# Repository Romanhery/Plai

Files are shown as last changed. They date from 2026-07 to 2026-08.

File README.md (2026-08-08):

# Plai-Hackpad
Plai is a 3x3 key macropad with a rotary encoder, an OLED Display. It uses KMK firmware
I made this so that I can learn PCB design, CAD, and Programming. It has upgraded and helped me with my experience.
# Features:
<ul>
   <li>128x32 OLED Display to show a cool message</li>
   <li>EC11 Rotary encoder to change volume</li>
   <li>9 keys for the shorcuts and media control</li>
</ul>
# PCB:
   <h2>Schematic</h2>
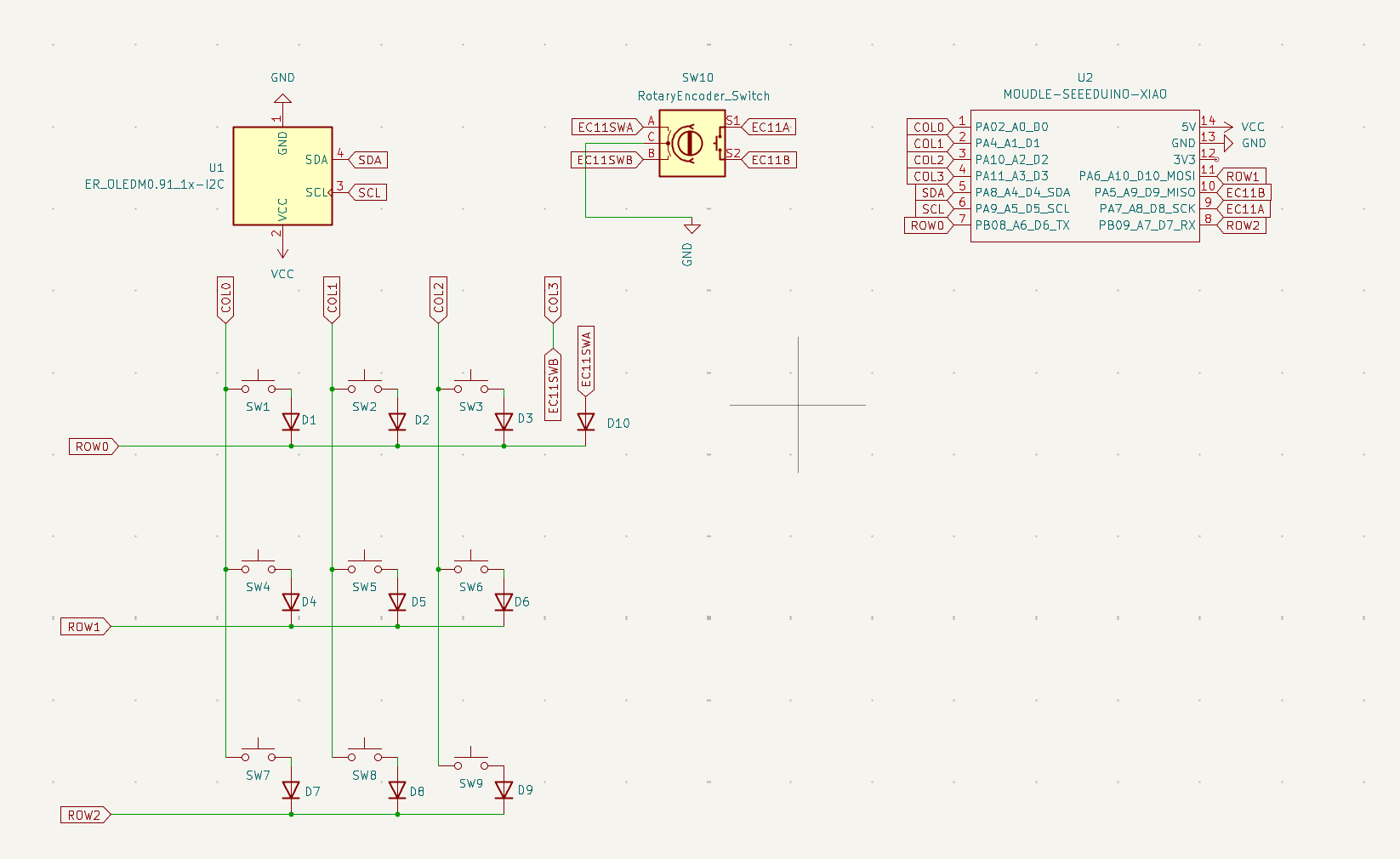
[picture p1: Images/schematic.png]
Schematic
   
   <h2>PCB</h2>
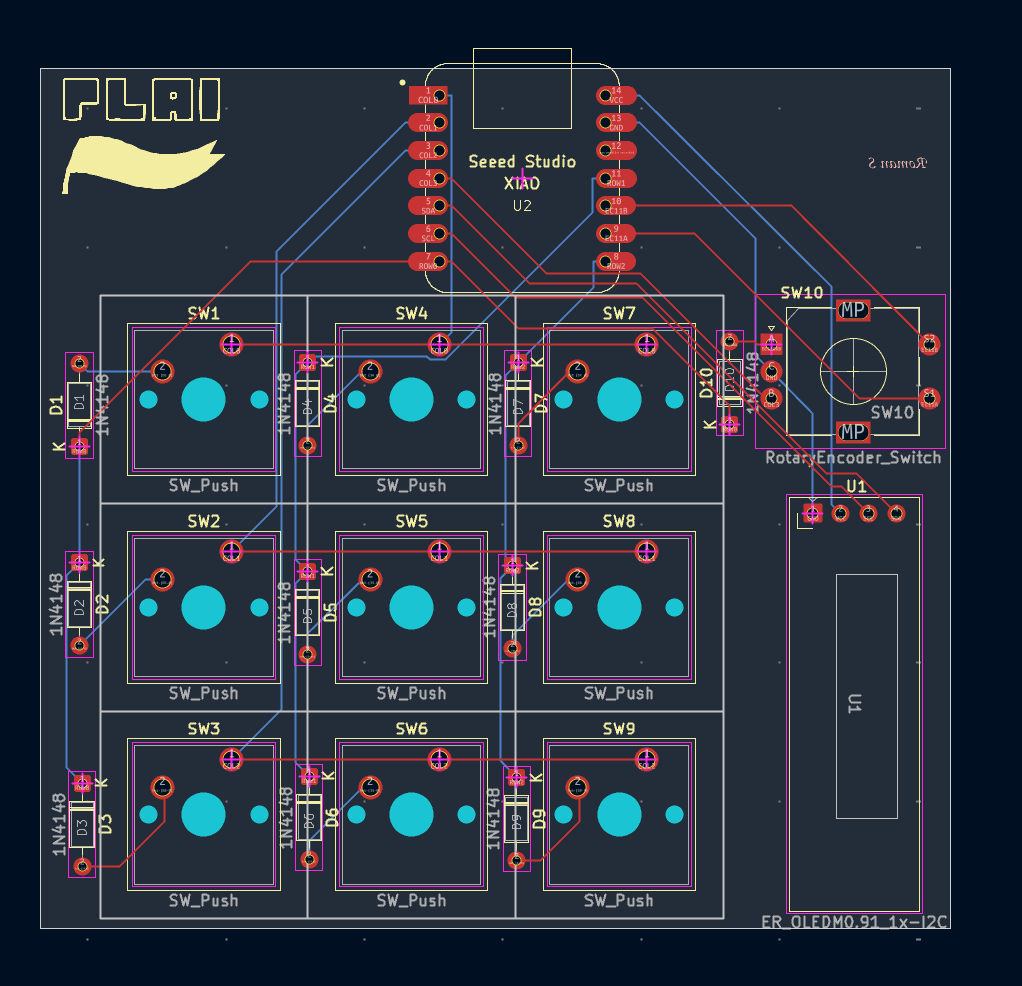
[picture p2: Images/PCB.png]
PCB
   
   <p>Made in <a href="https://www.kicad.org/">Ki-CAD</a></p> 

# CAD:
   <p>Everything is held together by using 5 M3 Bolts and heat inserts.</p>
   <p>It has 2 printed pieces to cover the electronics and house them.</p>
   <p>Made in Fusion 360</p>
<p align="center">
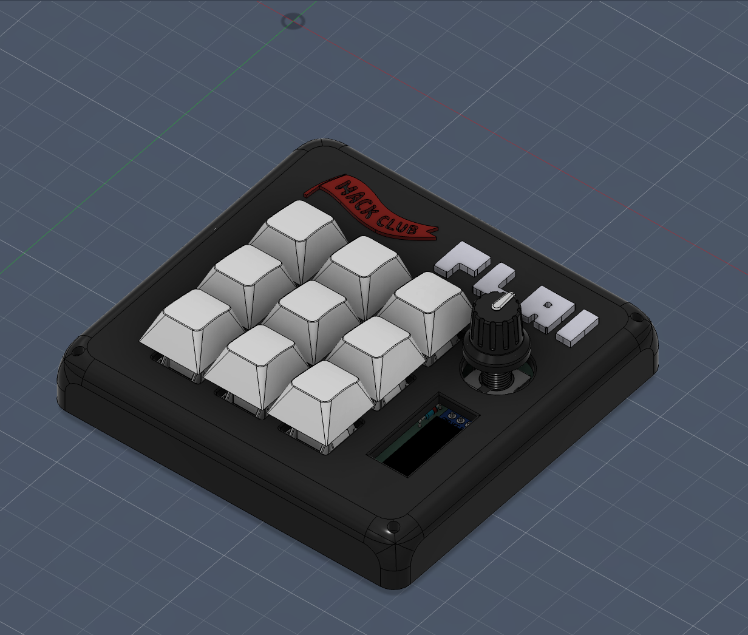
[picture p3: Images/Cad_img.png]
Plai CAD Render
  
</p>
# Firmware:
   <p>Made with <a href="https://github.com/KMKfw/kmk_firmware">KMK</a> firmware</p> 
   <h3>Features</h3>
   <li>Volume control if you twist the rotary encoder and if you press the encoder to mute</li>
   <li>Screen displays cool message</li>
   <li>They have macros for any shorcut you want (I have those right now for me)</li>
   <p align="center">
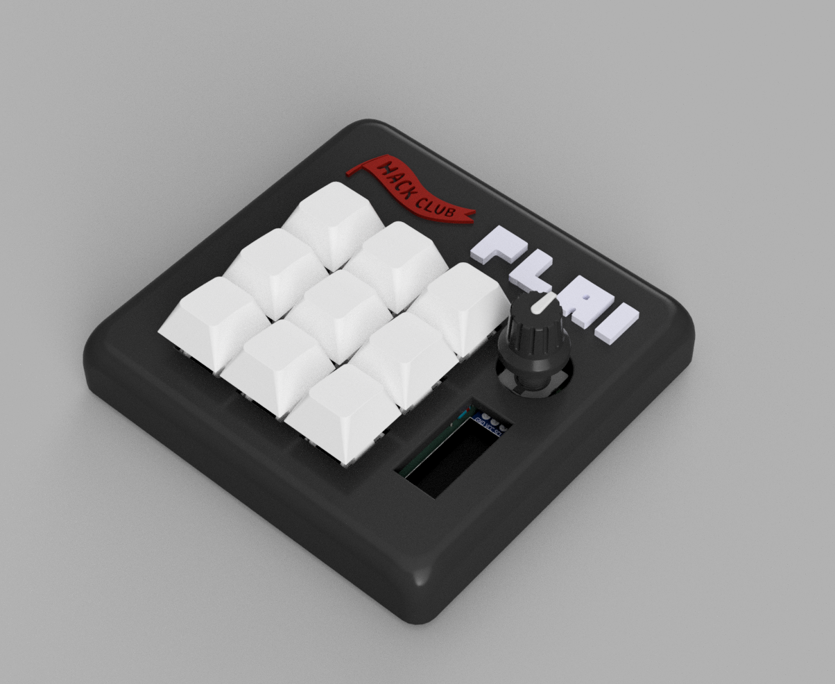
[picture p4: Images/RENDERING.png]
  
   </p>
# BOM:
<p>Everything you need to make this macro pad is here!</p>
<ul>
    <li>9x Cherry MX Switches</li>
    <li>9x DSA Keycaps</li>
    <li>5x M3x5x4 Heatset inserts</li>
    <li>4x M3x16mm SHCS Bolts</li>
    <li>9x 1N4148 DO-35 Diodes.</li>
    <li>1x 0.91" OLED Display</li>
    <li>1x EC11 Rotary Encoder</li>
    <li>1x XIAO RP2040</li>
    <li>1x Case (2 printed parts)</li>
   <a href="https://docs.google.com/spreadsheets/d/1uIeMTGPOrdSAiFDxR4G393WpXhlTQVRrd_AwqsaPwl4/edit?usp=sharing">BOM HERE WITH LINKS</a>
</ul>
## Acknowledgements

* [Orpheuspad](https://github.com/hackclub/hackpad/tree/main/cad/orpheuspad)
* [Keybie](https://github.com/Mirai-09/Keybie-Hackpads)
## Authors
- [@Romanhery](https://github.com/Romanhery)

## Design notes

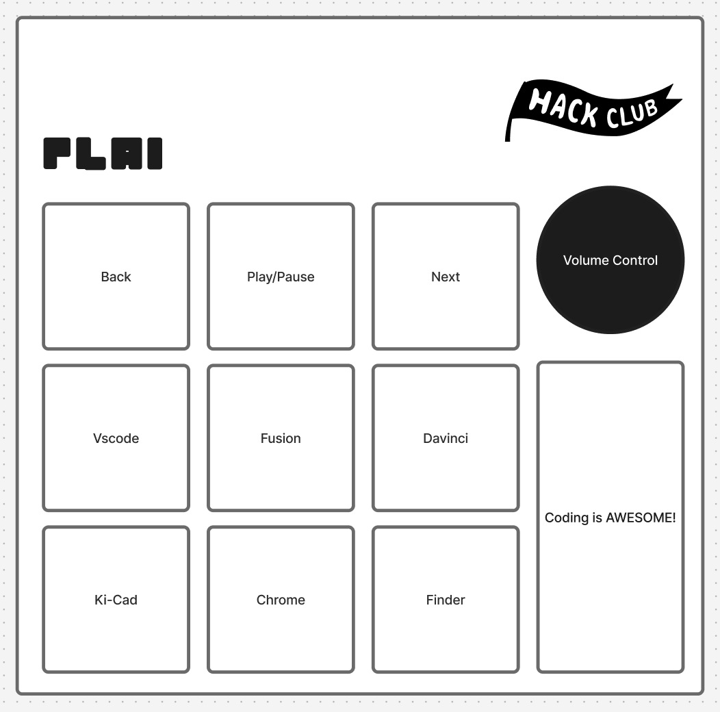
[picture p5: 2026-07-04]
Images/Initial_Design.png

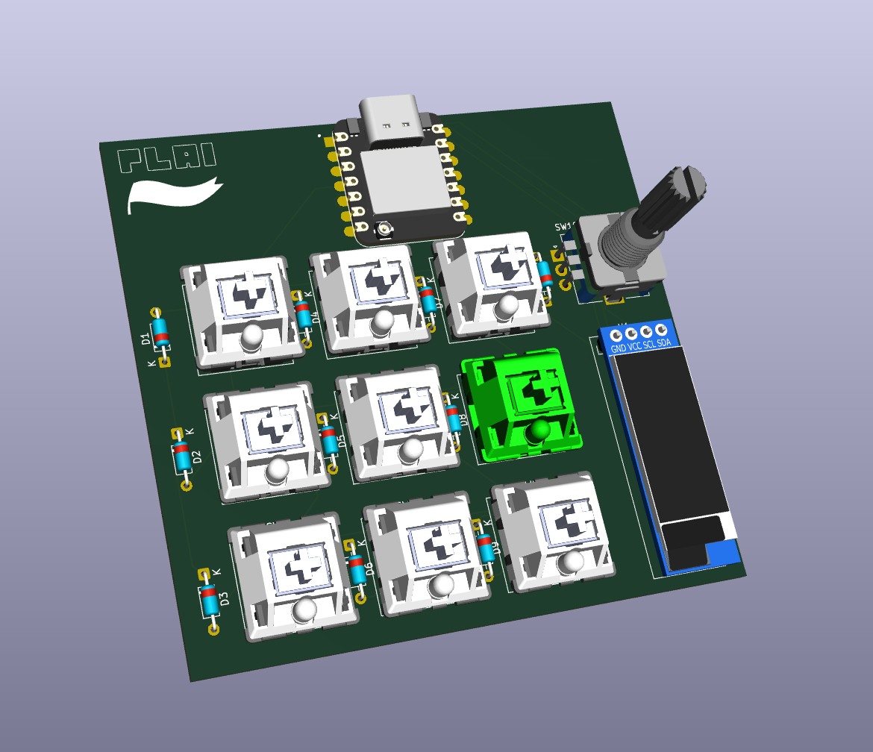
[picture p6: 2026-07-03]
Images/3d_pcb.png

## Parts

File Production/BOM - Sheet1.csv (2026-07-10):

Items | Price | Link
3d Printed Parts | $0.00
PCB | $5.30 | JLCPCB
MX cherry switches | $0.54 | Switches
DSA Keycaps | $2.79 | DSA CAPS
M3x5x4 Heatset inserts | $2.22 | Heated Inserts
XIAO-RP2040 | $4.92 | XIAO
1N4148 DO-35 Diodes | $1.04 | DIODES
0.91" OLED Display | $1.58 | Oled Screen
EC11 Rotary Encoder | $1.87 | Encoder
M3x16mm Bolts | $2.31 | Screws
TOTAL | $22.57

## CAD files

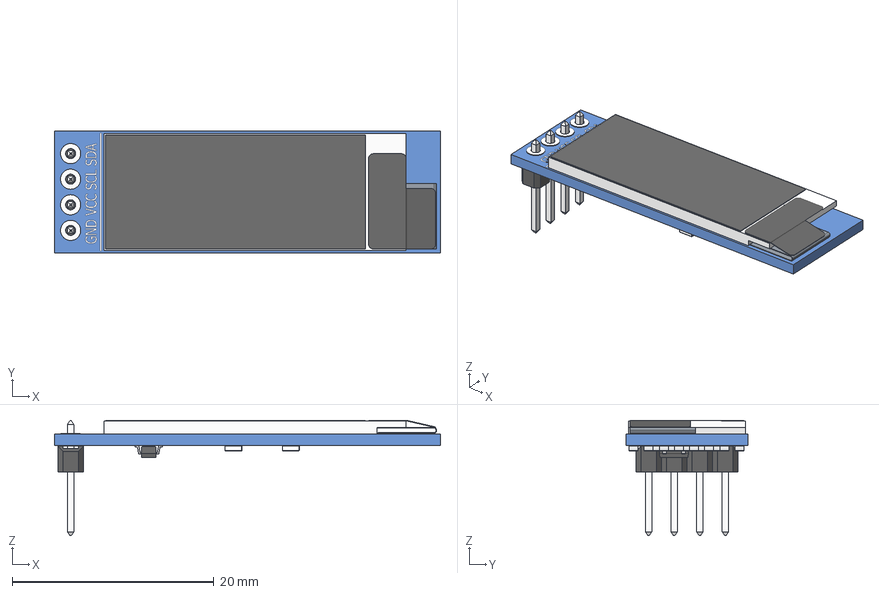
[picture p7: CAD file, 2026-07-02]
Case/3D_Models/OLED_0.91_128x32.stp
38.3 x 12.1 x 11.5 mm
OLED_0.91_128x32
Pin Header 4 x 1 TH 2.54mm Pitch
RESC-0603 x 13
2SD0601A

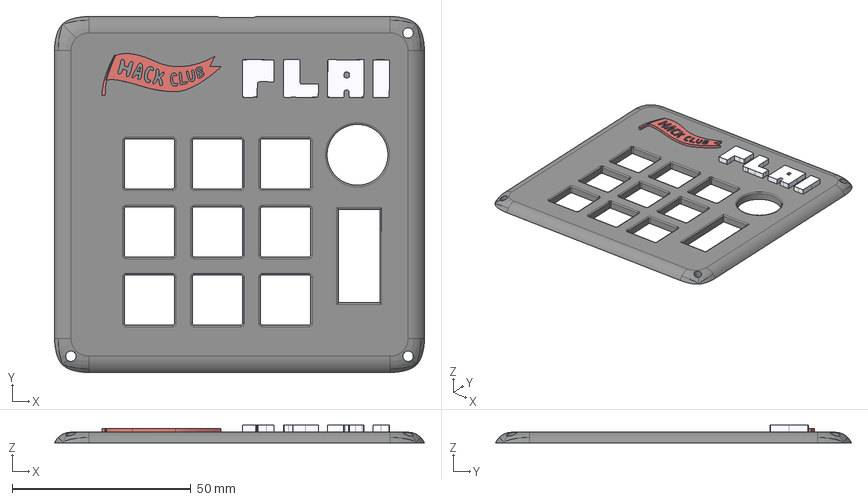
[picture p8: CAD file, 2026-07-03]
Case/TOP_CASE.step
103.5 x 99.6 x 5.00 mm

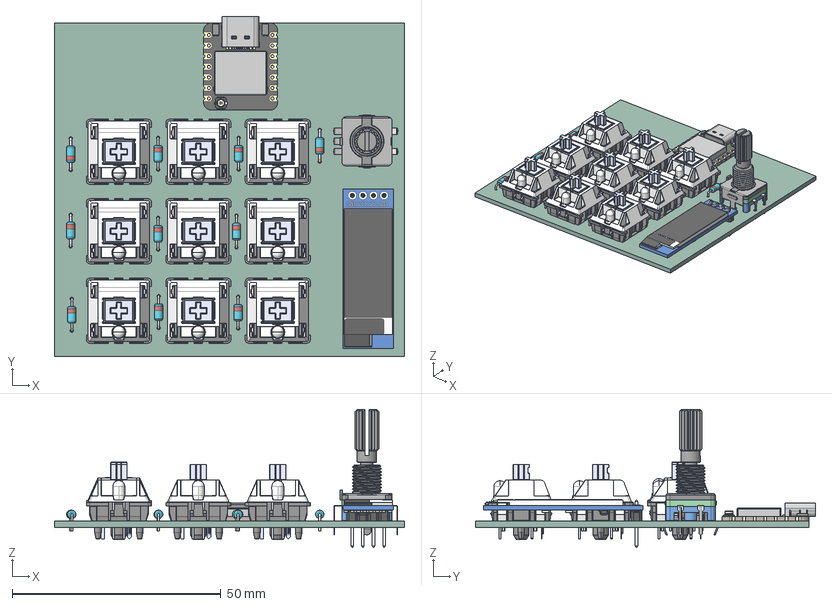
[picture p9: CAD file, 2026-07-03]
PCB/Plai-macro.step
83.9 x 81.5 x 33.1 mm
D_DO-35_SOD27_P7.62mm_Horizontal x 10
Bottom x 9
Pulsador x 9
Top x 9
Pieza5^Cherry MX x 9
Pin1 x 9
Pin2 x 9
Led 3mm_trans x 9
EC11_Rotary_Encoder_Switched
OLED_0.91_128x32
Pin Header 4 x 1 TH 2.54mm Pitch
RESC-0603 x 13
2SD0601A
BOSS-EXTRUDE14_8_
BOSS-EXTRUDE7_4_
BOSS-EXTRUDE7_3_
BOSS-EXTRUDE14_4_
BOSS-EXTRUDE14_2_
BOSS-EXTRUDE14_11_
BOSS-EXTRUDE7_7_
BOSS-EXTRUDE14_9_
BOSS-EXTRUDE14_3_
BOSS-EXTRUDE14_7_
MIRROR2
BOSS-EXTRUDE14_5_
BOSS-EXTRUDE14_12_
BOSS-EXTRUDE7_8_
BOSS-EXTRUDE7_1_
BOSS-EXTRUDE14_10_
BOSS-EXTRUDE7_9_
BOSS-EXTRUDE14_6_
BOSS-EXTRUDE14_1_
BOSS-EXTRUDE7_6_
BOSS-EXTRUDE7_2_
CUT-EXTRUDE5
BOSS-EXTRUDE7_5_
Shield
Pins x 2
U.FL-R-SMT-1_10_ v1
plai_PCB

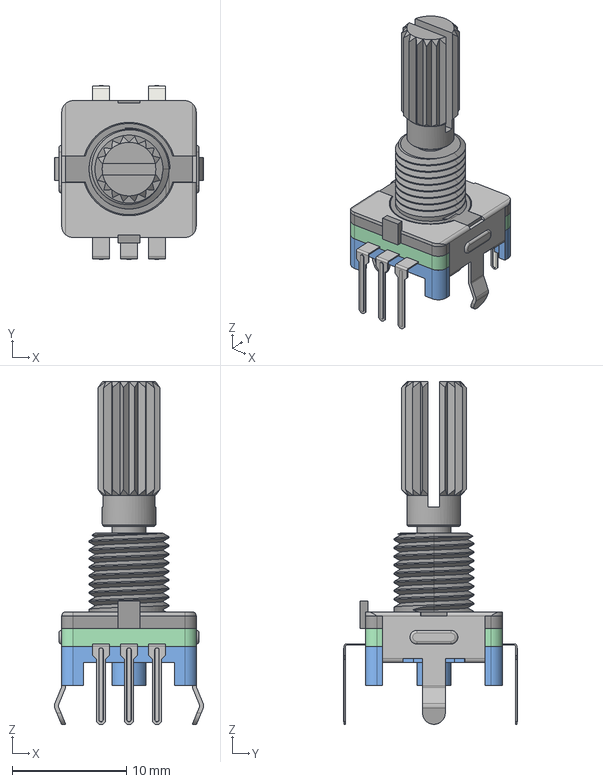
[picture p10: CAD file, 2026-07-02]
Case/3D_Models/EC11_Rotary_Encoder_Switched.step
13.1 x 15.3 x 30.1 mm

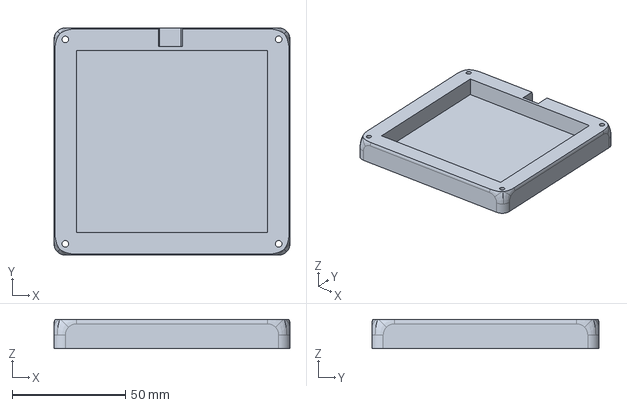
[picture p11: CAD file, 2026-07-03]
Case/BOTTOM_CASE.step
104.3 x 100.4 x 13.0 mm

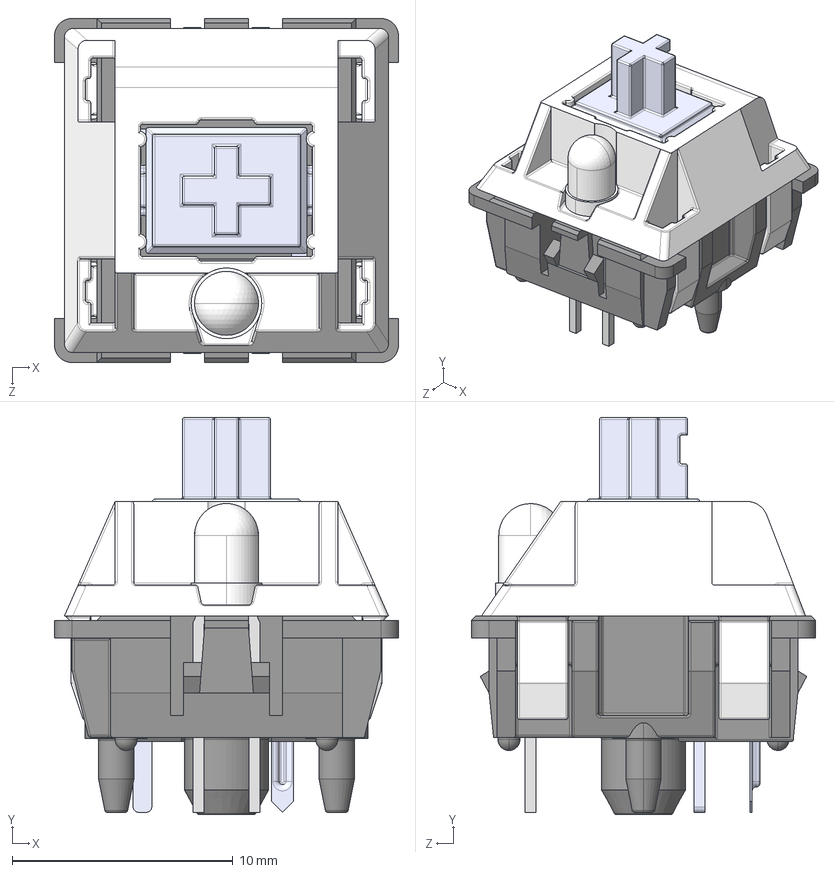
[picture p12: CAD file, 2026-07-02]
PCB/Cherry MX.STEP
15.6 x 18.0 x 15.6 mm
Bottom
Pulsador
Top
Pieza5^Cherry MX
Pin1
Pin2
Led 3mm_trans

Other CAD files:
Production/Top_Case.stl
Production/Bottom_Case.stl

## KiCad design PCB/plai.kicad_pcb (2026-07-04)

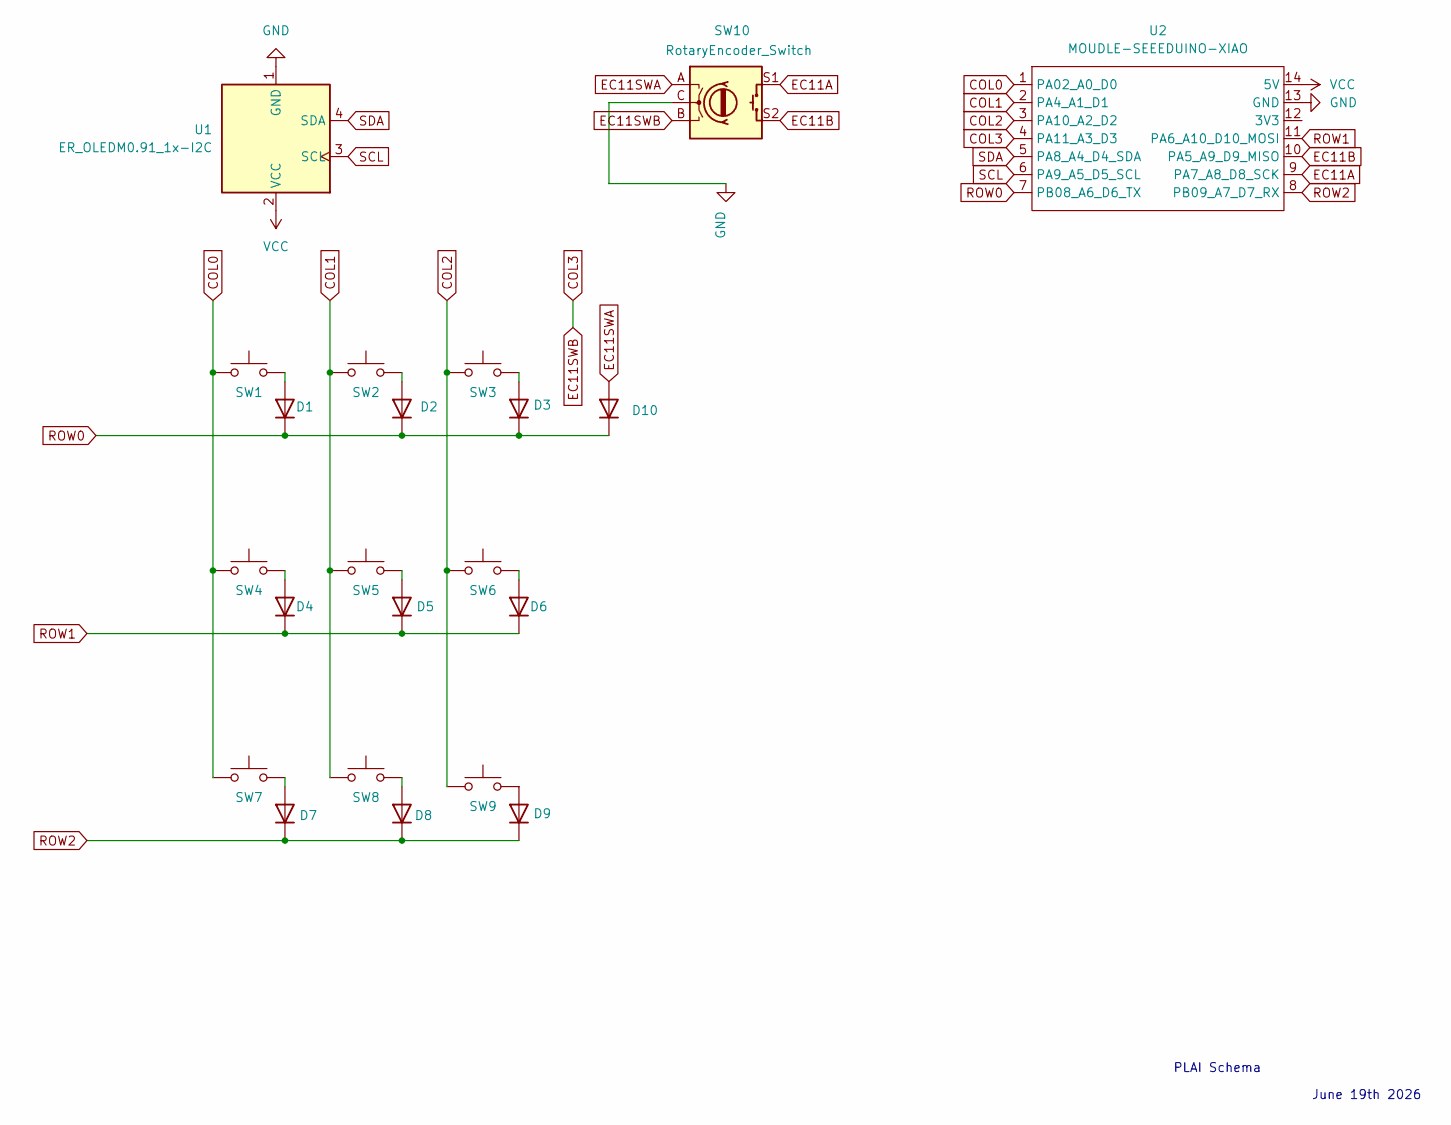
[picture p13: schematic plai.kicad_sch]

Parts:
D1, D2, D3, D4, D5, D6, D7, D8, D9, D10: 1N4148; D_DO-35_SOD27_P7.62mm_Horizontal
SW1, SW2, SW3, SW4, SW5, SW6, SW7, SW8, SW9: SW_Push; SW_Cherry_MX_1.00u_PCB
SW10: RotaryEncoder_Switch; RotaryEncoder_Alps_EC11E-Switch_Vertical_H20mm
U1: ER_OLEDM0.91_1x-I2C
U2: MOUDLE-SEEEDUINO-XIAO; XIAO-Generic-Hybrid-14P-2.54-21X17.8MM

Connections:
COL0: SW1.1, SW4.1, SW7.1, U2.1 (PA02_A0_D0)
COL1: SW2.1, SW5.1, SW8.1, U2.2 (PA4_A1_D1)
COL2: SW3.1, SW6.1, SW9.1, U2.3 (PA10_A2_D2)
COL3: SW10.B, U2.4 (PA11_A3_D3)
EC11A: SW10.S1, U2.9 (PA7_A8_D8_SCK)
EC11B: SW10.S2, U2.10 (PA5_A9_D9_MISO)
EC11SWA: D10.2 (A), SW10.A
GND: SW10.C, U1.1 (GND), U2.13 (GND)
unnamed: D1.2 (A), SW1.2
unnamed: D2.2 (A), SW2.2
unnamed: D3.2 (A), SW3.2
unnamed: D4.2 (A), SW4.2
unnamed: D5.2 (A), SW5.2
unnamed: D6.2 (A), SW6.2
unnamed: D7.2 (A), SW7.2
unnamed: D8.2 (A), SW8.2
unnamed: D9.2 (A), SW9.2
ROW0: D1.1 (K), D2.1 (K), D3.1 (K), D10.1 (K), U2.7 (PB08_A6_D6_TX)
ROW1: D4.1 (K), D5.1 (K), D6.1 (K), U2.11 (PA6_A10_D10_MOSI)
ROW2: D7.1 (K), D8.1 (K), D9.1 (K), U2.8 (PB09_A7_D7_RX)
SCL: U1.3 (SCL), U2.6 (PA9_A5_D5_SCL)
SDA: U1.4 (SDA), U2.5 (PA8_A4_D4_SDA)
VCC: U1.2 (VCC), U2.14 (5V)

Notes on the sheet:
PLAI Schema
June 19th 2026

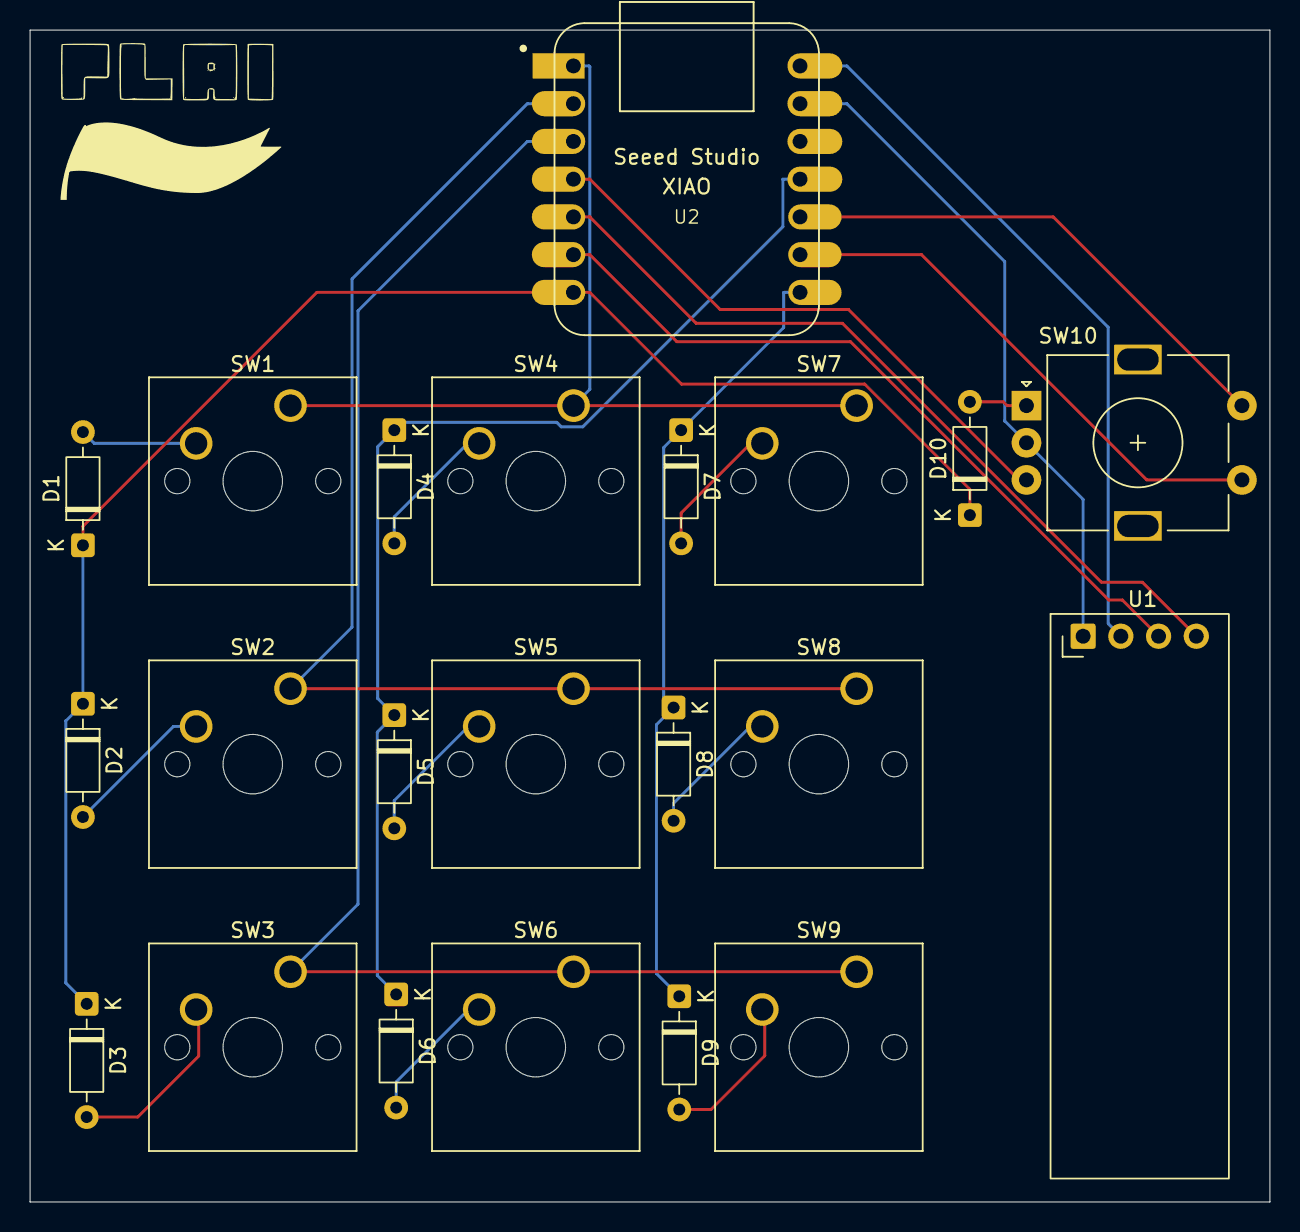
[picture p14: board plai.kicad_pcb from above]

Board: 2 copper layers, 83.4 x 78.9 mm, 22 parts (0 on the bottom side), 23 nets.

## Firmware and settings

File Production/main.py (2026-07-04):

"""
Plai MacroPad

Roman
"""
print("Starting")

#Libraries
import board

from kmk.kmk_keyboard import KMKKeyboard
from kmk.keys import KC
from kmk.scanners import DiodeOrientation
from kmk.modules.encoder import EncoderHandler
from kmk.extensions.display import Display , TextEntry
from kmk.extensions.display.ssd1306 import SSD1306
from kmk.extensions.media_keys import MediaKeys

#Pin Definitons
COL0 = board.D0
COL1 = board.D1
COL2 = board.D2
COL3 = board.D3
SDA = board.D4
SCL = board.D5
ROW0 = board.D6
ROW1 = board.D10
ROW2 = board.D7
EC11B = board.D9
EC11A = board.D8

keyboard = KMKKeyboard()

#Maping out the rows and the collums and what orientation the diodes are
keyboard.col_pins = (COL0,COL1,COL2,COL3)
keyboard.row_pins = (ROW0,ROW1,ROW2)
keyboard.diode_orientation = DiodeOrientation.COL2ROW

encoder_handler = EncoderHandler()


#just adding the modules to the keyboard
keyboard.modules.append(encoder_handler)
keyboard.extensions.append(MediaKeys())

#Maping out the pins and the keys of the encoder
encoder_handler.pins = ((EC11A, EC11B, None, False),)
encoder_handler.map = (((KC.VOLD, KC.VOLU),),)

#mapping out all of the keys
keyboard.keymap = [
    [
        #Row 0
        KC.MPRV, #Previous Song
        KC.MPLY, #Play the Song
        KC.MNXT,  #Next Song
        KC.MUTE, #Mute Song

        #Row 1
        KC.LCTRL(KC.LALT(KC.LCMD(KC.LSHIFT(KC.V)))), # Vscode
        KC.LCTRL(KC.LALT(KC.LCMD(KC.LSHIFT(KC.F)))), # Fusion
        KC.LCTRL(KC.LALT(KC.LCMD(KC.LSHIFT(KC.D)))), # Davionci Resolve
        KC.NO,        # Empty matrix slot: We did this because the encoder doesnt have its own pin and we connected it to the matrix

        # ROW 2
        KC.LCTRL(KC.LALT(KC.LCMD(KC.LSHIFT(KC.K)))), # Ki Cad
        KC.LCTRL(KC.LALT(KC.LCMD(KC.LSHIFT(KC.C)))), # Chrome
        KC.LCTRL(KC.LALT(KC.LCMD(KC.LSHIFT(KC.F12)))),# Finder
        KC.NO,        # Empty matrix slot
    ]
]

#displays Coding Is Awesome!!!
display = Display(
    #Pin maping
    display=SSD1306(sda=SDA,scl=SCL),
    #What should go into the display
    entries=[
        #The actual text Coding is awesome
        TextEntry(text='Coding Is Awesome!!!')
    ],
    #how tall it should be
    height=32
)
#enter it into the actual display and show it
keyboard.extensions.append(display)

if __name__ == '__main__':
    keyboard.go()

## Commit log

2026-07-02 initial commit: pristine design and hardware files
    [Bottom_Case.step, EC11_Rotary_Encoder_Switched.step, OLED_0.91_128x32.stp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]
2026-07-02 Added 3d models to the PCB
    [Cherry MX.STEP, plai.kicad_pcb]
2026-07-02 Added 3d models
    [Cherry MX.STEP]
2026-07-03 Updated Case With USBC hole and new images of the pcbs
    [BEST_BOTTOM_CASE.step, BEST_TOP_CASE.step, Plai-macro.step]
2026-07-03 Fullyt Routed PCB Beautifully Routed + Some additions ot the firmware
    [PLAIs.dsn, plai.dsn, plai.kicad_pcb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]
2026-07-04 New Read me with BOM
2026-07-04 Production files + gerber files
    [Bottom_Case.step, Top_Case.step, plai.kicad_pcb]
2026-07-10 Added BOM
    [BOM - Sheet1.csv]
2026-07-10 Update BOM - Sheet1.csv
    [BOM - Sheet1.csv]
2026-08-08 Add BOTTOM_CASE.step file
    [BOTTOM_CASE.step]
2026-08-13 Added STL FILES FOR 3d printing
    [Bottom_Case.stl, Top_Case.stl]
